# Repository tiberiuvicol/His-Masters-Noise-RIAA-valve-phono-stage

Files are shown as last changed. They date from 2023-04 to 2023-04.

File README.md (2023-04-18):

# His Master's Noise a high quality RIAA valve phono stage

This is a simple PCB designed in KiCad for His Master's Noise phono stage.</br>
https://www.diyaudio.com/community/threads/his-masters-noise-a-thoroughly-modern-tube-phono-preamp.163570/</br>
PCB's are for power supply and separate left/right channels.</br>
Install KiCad, download project, open HMN.kicad_pro and hmn_ps.kicad_pro

</br>


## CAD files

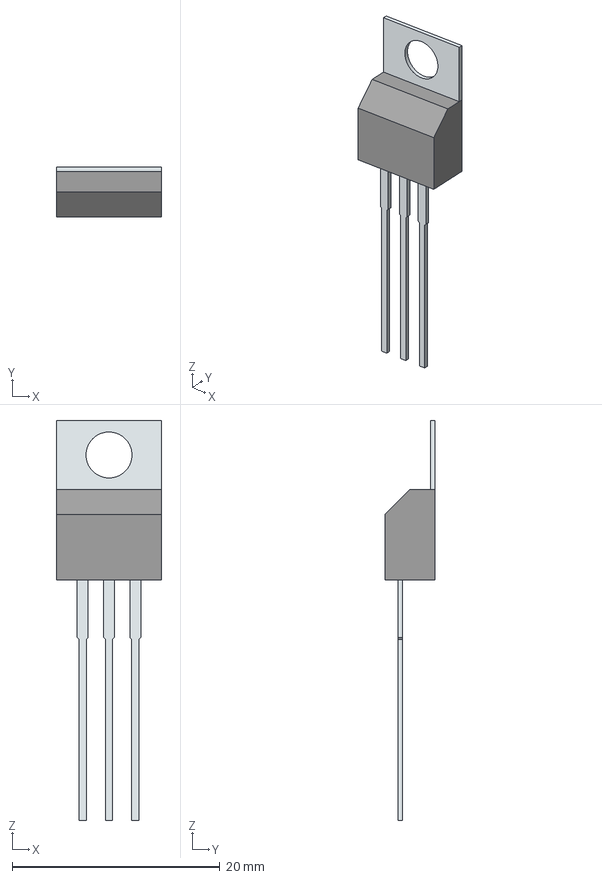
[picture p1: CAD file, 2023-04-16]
DN2540N5.stp
10.2 x 4.83 x 38.5 mm
Tab
PinsArray

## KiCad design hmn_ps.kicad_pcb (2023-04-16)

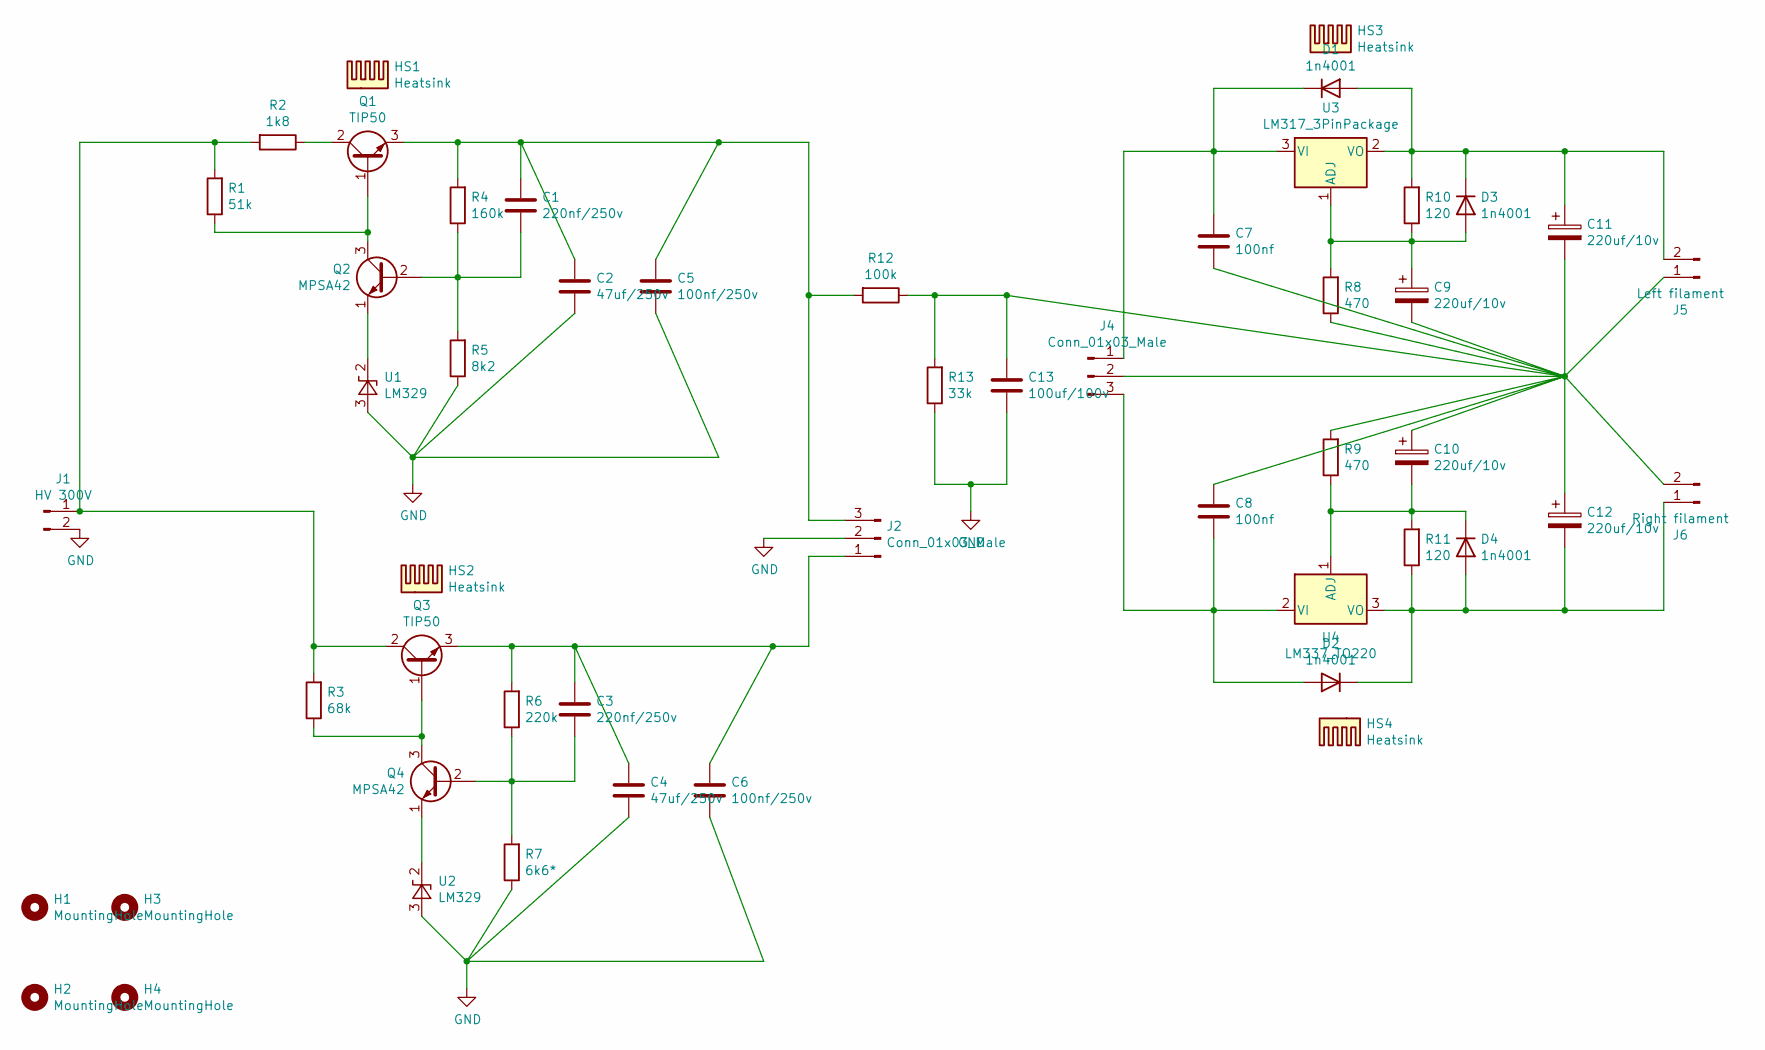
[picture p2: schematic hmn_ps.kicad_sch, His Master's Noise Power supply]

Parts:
C1, C3: 220nf/250v; C_Rect_L13.0mm_W6.0mm_P10.00mm_FKS3_FKP3_MKS4
C2, C4: 47uf/250v; CP_Radial_D18.0mm_P7.50mm
C5, C6: 100nf/250v; C_Rect_L13.0mm_W4.0mm_P10.00mm_FKS3_FKP3_MKS4
C7, C8: 100nf; C_Rect_L7.5mm_W6.5mm_P5.00mm
C9, C10, C11, C12: 220uf/10v; C_Radial_D6.3mm_H11.0mm_P2.50mm
C13: 100uf/100v; CP_Radial_D18.0mm_P7.50mm
D1, D2, D3, D4: 1n4001; D_DO-41_SOD81_P7.62mm_Horizontal
H1, H2, H3, H4: MountingHole; MountingHole_3.2mm_M3_Pad_Via
HS1, HS2: Heatsink; Heatsink_Fischer_SK104-STC-STIC_35x13mm_2xDrill2.5mm
HS3, HS4: Heatsink; Heatsink_Fischer_SK129-STS_42x25mm_2xDrill2.5mm
J1: HV 300V; TerminalBlock_Altech_AK300-2_P5.00mm
J2, J4: Conn_01x03_Male; TerminalBlock_Altech_AK300-3_P5.00mm
J5: Left filament; TerminalBlock_Altech_AK300-2_P5.00mm
J6: Right filament; TerminalBlock_Altech_AK300-2_P5.00mm
Q1, Q3: TIP50; TO-220-3_Vertical
Q2, Q4: MPSA42; TO-92_Inline
R1: 51k; R_Axial_DIN0207_L6.3mm_D2.5mm_P10.16mm_Horizontal
R2: 1k8; R_Axial_DIN0414_L11.9mm_D4.5mm_P20.32mm_Horizontal
R3: 68k; R_Axial_DIN0207_L6.3mm_D2.5mm_P10.16mm_Horizontal
R4: 160k; R_Axial_DIN0207_L6.3mm_D2.5mm_P10.16mm_Horizontal
R5: 8k2; R_Axial_DIN0207_L6.3mm_D2.5mm_P10.16mm_Horizontal
R6: 220k; R_Axial_DIN0207_L6.3mm_D2.5mm_P10.16mm_Horizontal
R7: 6k6*; R_Axial_DIN0207_L6.3mm_D2.5mm_P10.16mm_Horizontal
R8, R9: 470; R_Axial_DIN0207_L6.3mm_D2.5mm_P10.16mm_Horizontal
R10, R11: 120; R_Axial_DIN0207_L6.3mm_D2.5mm_P10.16mm_Horizontal
R12: 100k; R_Axial_DIN0414_L11.9mm_D4.5mm_P20.32mm_Horizontal
R13: 33k; R_Axial_DIN0207_L6.3mm_D2.5mm_P10.16mm_Horizontal
U1, U2: LM329; TO-92_Inline_Wide
U3: LM317_3PinPackage; TO-220F-3_Vertical
U4: LM337_TO220; TO-220F-3_Vertical

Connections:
GND: C2.2, C4.2, C5.2, C6.2, C13.2, J1.2, J2.2, R5.1, R7.1, R13.1, U1.3 (A), U2.3 (A)
unnamed: C1.1, C2.1, C5.1, J2.3, Q1.3 (E), R4.2, R12.2
unnamed: C1.2, Q2.2 (B), R4.1, R5.2
unnamed: C3.1, C4.1, C6.1, J2.1, Q3.3 (E), R6.2
unnamed: C3.2, Q4.2 (B), R6.1, R7.2
unnamed: C7.1, D1.1 (K), J4.1, U3.3 (VI)
unnamed: C8.2, D2.2 (A), J4.3, U4.2 (VI)
unnamed: C9.1, D3.2 (A), R8.2, R10.1, U3.1 (ADJ)
unnamed: C7.2, C8.1, C9.2, C10.1, C11.2, C12.1, C13.1, J4.2, J5.1, J6.2, R8.1, R9.2, R12.1, R13.2
unnamed: C10.2, D4.1 (K), R9.1, R11.2, U4.1 (ADJ)
unnamed: C11.1, D1.2 (A), D3.1 (K), J5.2, R10.2, U3.2 (VO)
unnamed: C12.2, D2.1 (K), D4.2 (A), J6.1, R11.1, U4.3 (VO)
unnamed: J1.1, Q3.2 (C), R1.2, R2.2, R3.2
unnamed: Q1.1 (B), Q2.3 (C), R1.1
unnamed: Q1.2 (C), R2.1
unnamed: Q2.1 (E), U1.2 (K)
unnamed: Q3.1 (B), Q4.3 (C), R3.1
unnamed: Q4.1 (E), U2.2 (K)

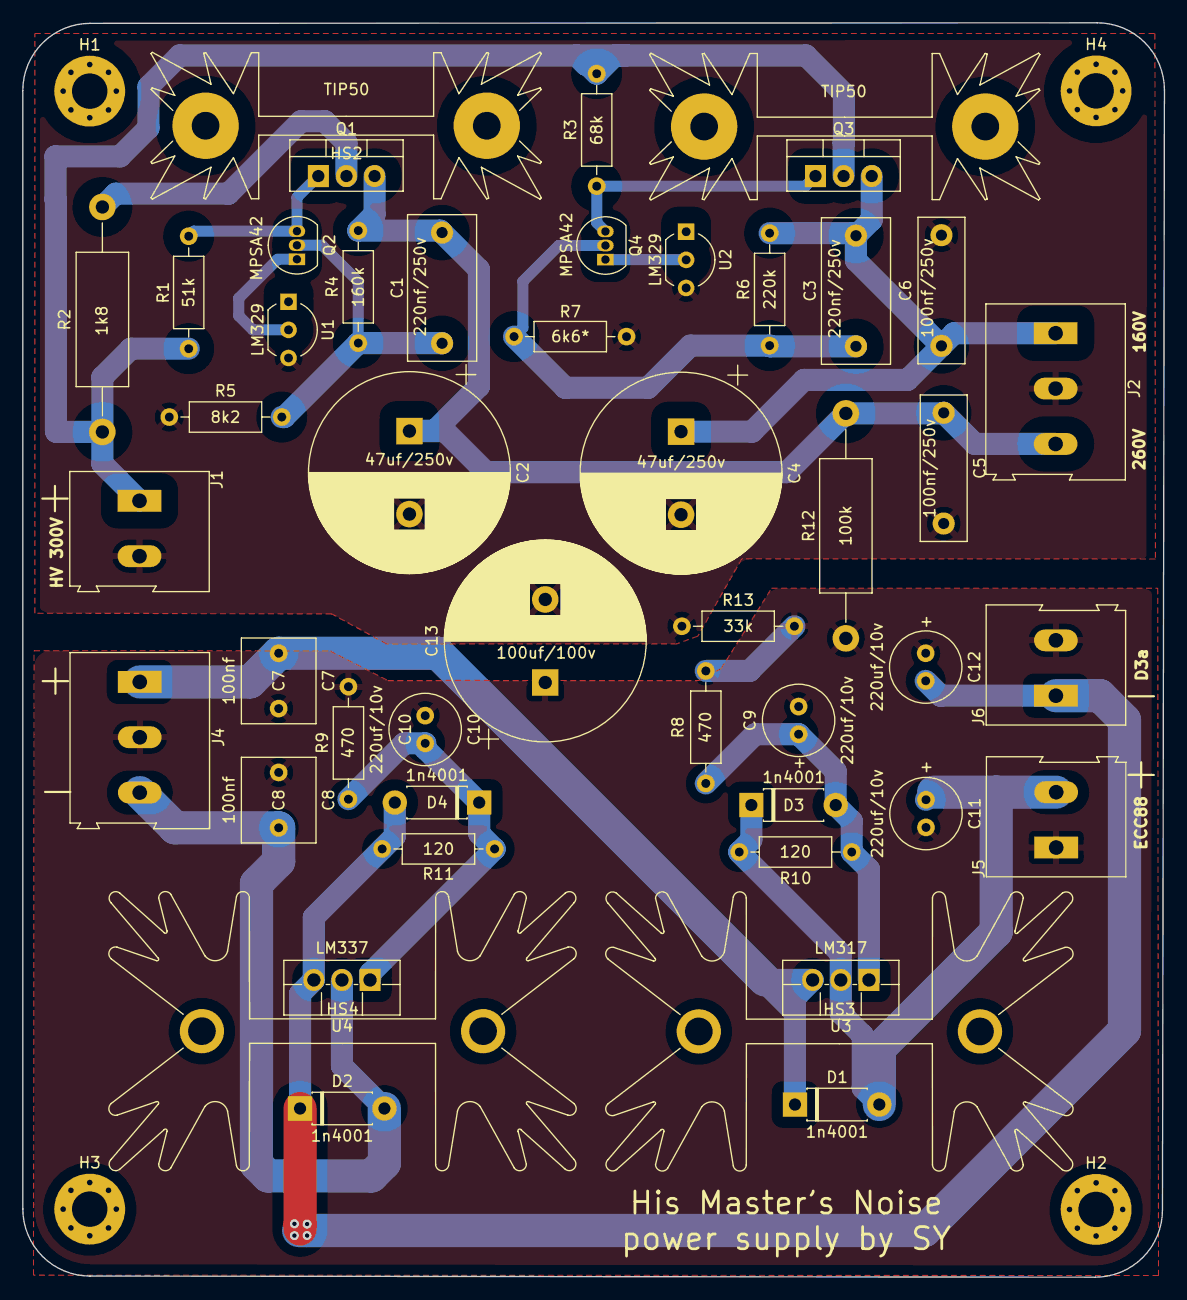
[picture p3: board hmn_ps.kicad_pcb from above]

Board: 2 copper layers, 103.1 x 113.3 mm, 51 parts (0 on the bottom side), 18 nets.

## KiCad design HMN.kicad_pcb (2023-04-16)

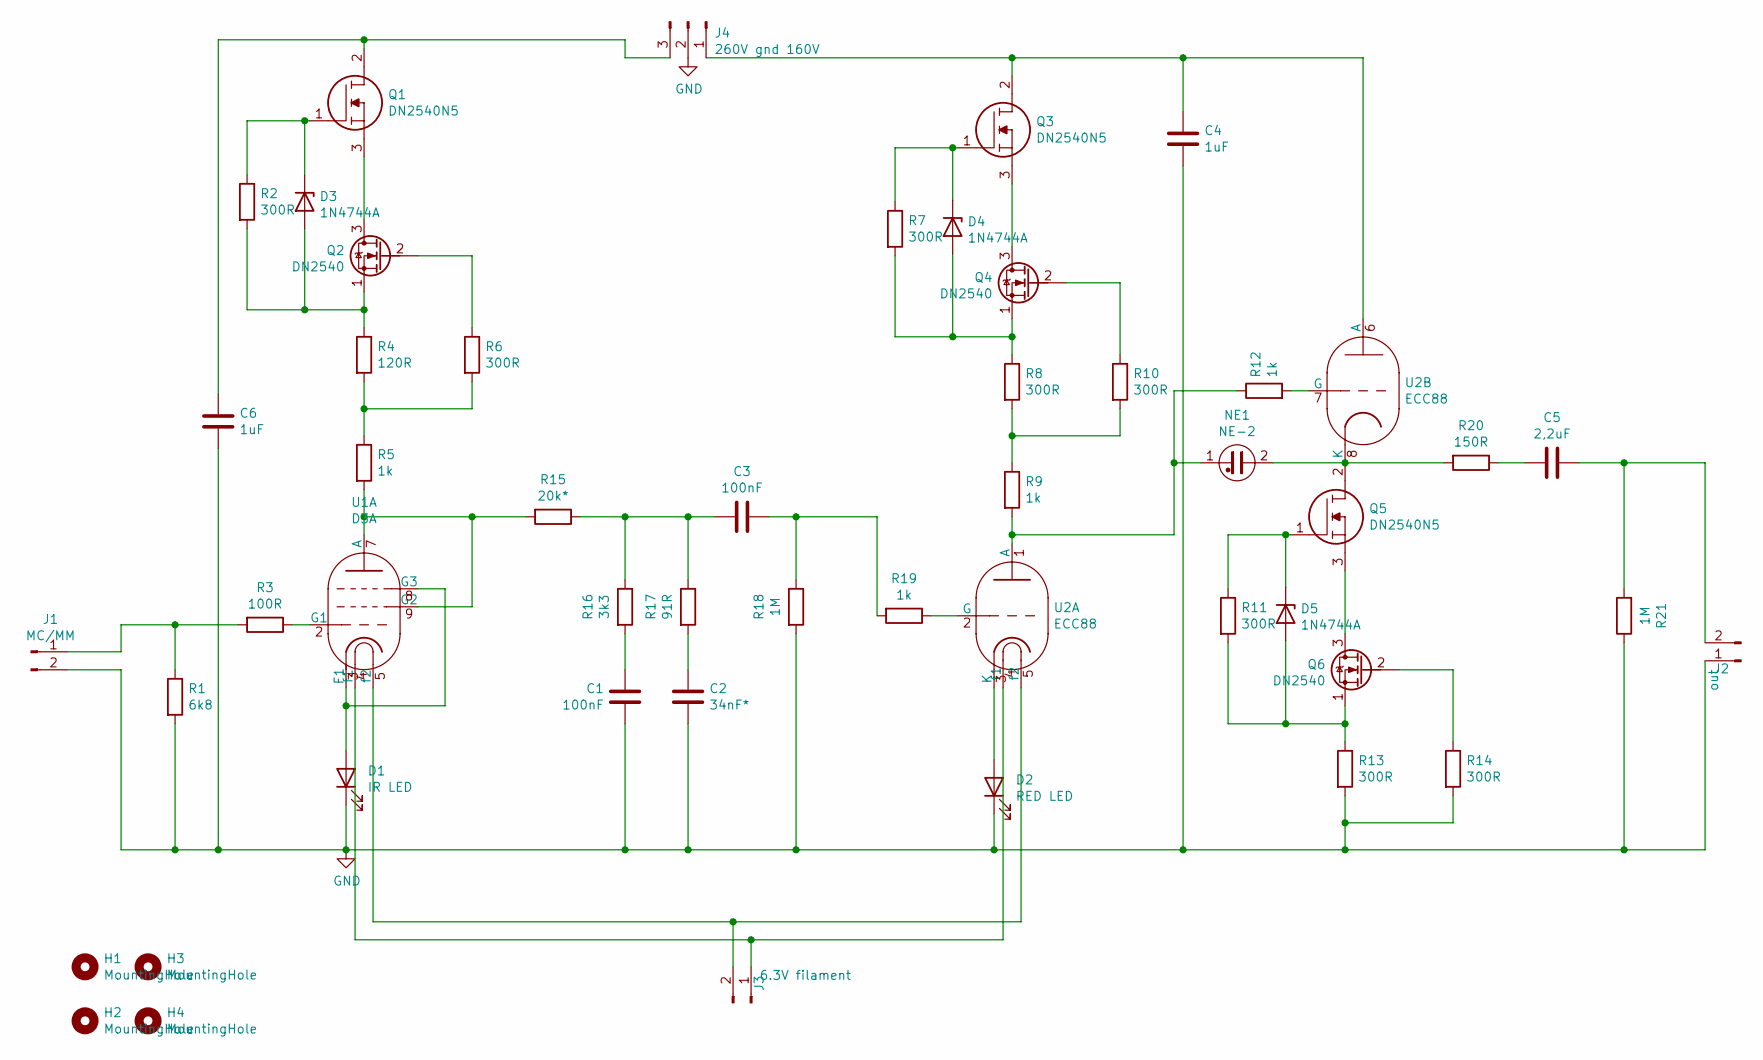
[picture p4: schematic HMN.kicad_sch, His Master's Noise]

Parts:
C1, C3: 100nF; C_Rect_L16.5mm_W7.3mm_P15.00mm_MKT
C2: 34nF*; C_Rect_L16.5mm_W7.3mm_P15.00mm_MKT
C4, C6: 1uF; C_Rect_L31.5mm_W20.0mm_P27.50mm_MKS4
C5: 2,2uF; C_Rect_L31.5mm_W20.0mm_P27.50mm_MKS4
D1: IR LED; LED_D3.0mm_IRBlack
D2: RED LED; LED_D3.0mm_IRGrey
D3, D4, D5: 1N4744A; D_DO-41_SOD81_P10.16mm_Horizontal
H1, H2, H3, H4: MountingHole; MountingHole_3.2mm_M3_Pad_Via
J1: MC/MM; TerminalBlock_Altech_AK300-2_P5.00mm
J2: out; TerminalBlock_Altech_AK300-2_P5.00mm
J3: 6.3V filament; TerminalBlock_Altech_AK300-2_P5.00mm
J4: 260V gnd 160V; TerminalBlock_Altech_AK300-3_P5.00mm
NE1: NE-2; LED_D5.0mm
Q1, Q3, Q5: DN2540N5; TO254P483X1016X2375-3P; Mouser Part Number 689-DN2540N5
Q2, Q4, Q6: DN2540; TO-92L_Inline_Wide
R1: 6k8; R_Axial_DIN0207_L6.3mm_D2.5mm_P10.16mm_Horizontal
R2, R6, R7, R8, R10, R11, R13, R14: 300R; R_Axial_DIN0207_L6.3mm_D2.5mm_P10.16mm_Horizontal
R3: 100R; R_Axial_DIN0207_L6.3mm_D2.5mm_P10.16mm_Horizontal
R4: 120R; R_Axial_DIN0207_L6.3mm_D2.5mm_P10.16mm_Horizontal
R5, R9, R12, R19: 1k; R_Axial_DIN0207_L6.3mm_D2.5mm_P10.16mm_Horizontal
R15: 20k*; R_Axial_DIN0207_L6.3mm_D2.5mm_P10.16mm_Horizontal
R16: 3k3; R_Axial_DIN0207_L6.3mm_D2.5mm_P10.16mm_Horizontal
R17: 91R; R_Axial_DIN0207_L6.3mm_D2.5mm_P10.16mm_Horizontal
R18, R21: 1M; R_Axial_DIN0207_L6.3mm_D2.5mm_P10.16mm_Horizontal
R20: 150R; R_Axial_DIN0207_L6.3mm_D2.5mm_P10.16mm_Horizontal
U1: D3A; Valve_ECC-83-2
U2: ECC88; Valve_ECC-83-2

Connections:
GND: C1.1, C2.1, C4.2, C6.2, D1.1 (K), D2.1 (K), J1.2, J2.1, J4.2, R1.2, R13.2, R14.2, R18.2, R21.1; also elsewhere on the board
unnamed 1: C1.2, R16.2; also elsewhere on the board
unnamed: C2.2, R17.2
unnamed 3: C3.1, R15.1, R16.1, R17.1; also elsewhere on the board
unnamed 4: C3.2, R18.1, R19.2; also elsewhere on the board
unnamed: C4.1, J4.1, Q3.2, U2.6 (A)
unnamed: C5.1, J2.2, R21.2
unnamed: C5.2, R20.1
unnamed: C6.1, J4.3, Q1.2
unnamed: D1.2 (A), U1.3 (F1), U1.8 (G3)
unnamed: D2.2 (A), U2.3 (K)
unnamed: D3.1 (K), Q1.1, R2.1
unnamed: D3.2 (A), Q2.1 (S), R2.2, R4.1
unnamed: D4.1 (K), Q3.1, R7.1
unnamed: D4.2 (A), Q4.1 (S), R7.2, R8.1
unnamed: D5.1 (K), Q5.1, R11.1
unnamed: D5.2 (A), Q6.1 (S), R11.2, R13.1
unnamed 17: J1.1, R1.1, R3.2; also elsewhere on the board
unnamed: J3.1, U1.4 (f1), U2.4 (f1)
unnamed: J3.2, U1.5 (f2), U2.5 (f2)
unnamed: NE1.1, R9.2, R12.1, U2.1 (A)
unnamed: NE1.2, Q5.2, R20.2, U2.8 (K)
unnamed: Q1.3, Q2.3 (D)
unnamed: Q2.2 (G), R6.1
unnamed: Q3.3, Q4.3 (D)
unnamed: Q4.2 (G), R10.1
unnamed: Q5.3, Q6.3 (D)
unnamed: Q6.2 (G), R14.1
unnamed: R3.1, U1.2 (G1)
unnamed: R4.2, R5.1, R6.2
unnamed: R8.2, R9.1, R10.2
unnamed: R12.2, U2.7 (G)
unnamed: R5.2, R15.2, U1.7 (A), U1.9 (G2)
unnamed: R19.1, U2.2 (G)

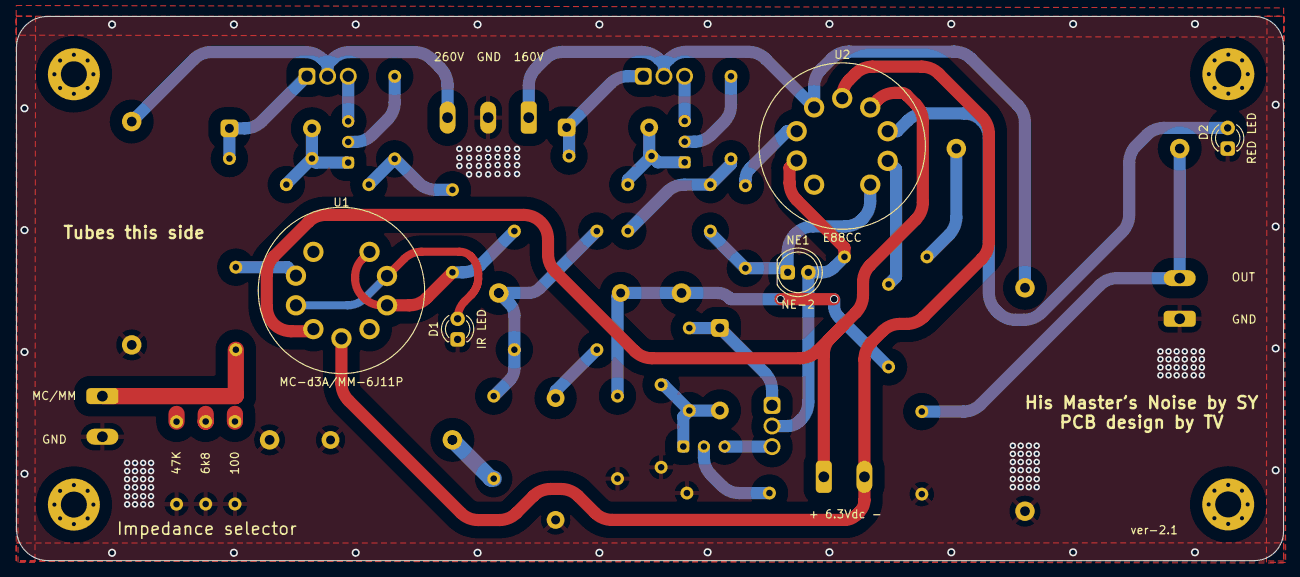
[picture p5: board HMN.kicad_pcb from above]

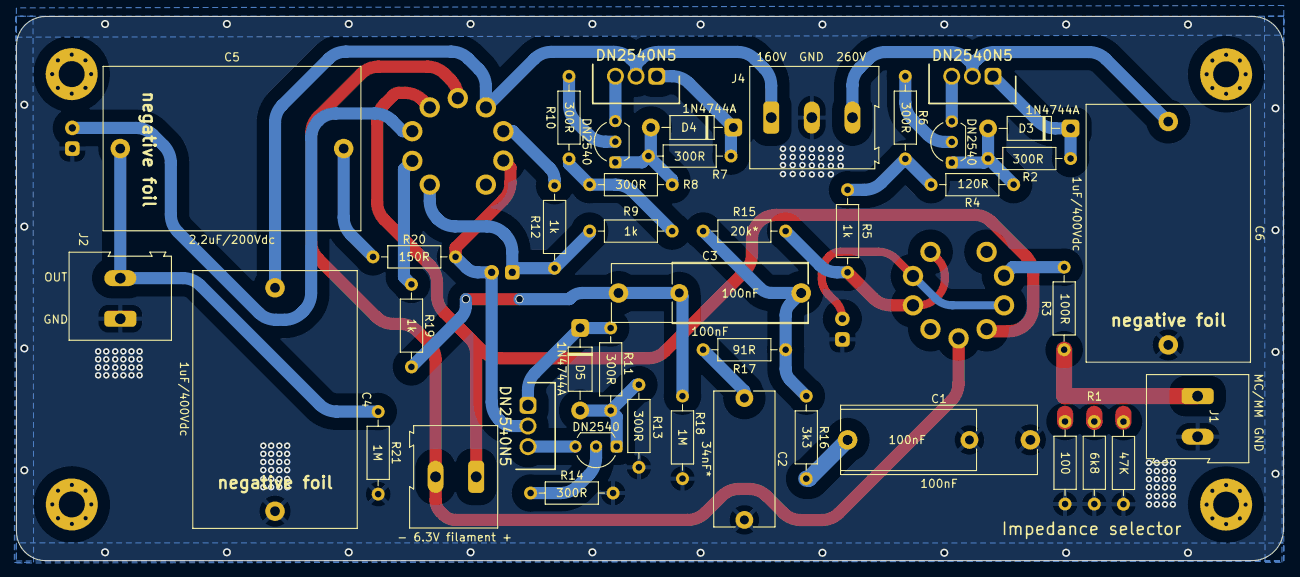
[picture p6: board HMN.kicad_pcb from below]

Board: 2 copper layers, 156.0 x 67.0 mm, 53 parts (44 on the bottom side), 34 nets.

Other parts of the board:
C1#2: 100nF; C_Rect_L24.0mm_W8.3mm_P22.50mm_MKT
C3#2: 100nF; C_Rect_L24.0mm_W7.0mm_P22.50mm_MKT
R1#2: 100; R_Axial_DIN0207_L6.3mm_D2.5mm_P10.16mm_Horizontal
R1#3: 6k8; R_Axial_DIN0207_L6.3mm_D2.5mm_P10.16mm_Horizontal

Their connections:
GND: C1#2.1, R1#2.2, R1#3.2; also elsewhere on the board
unnamed 1: C1#2.2; also elsewhere on the board
unnamed 3: C3#2.1; also elsewhere on the board
unnamed 4: C3#2.2; also elsewhere on the board
unnamed 17: R1#2.1, R1#3.1; also elsewhere on the board
